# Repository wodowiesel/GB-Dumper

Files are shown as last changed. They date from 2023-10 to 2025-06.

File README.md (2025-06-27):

# GB-Dumper - Gameboy Cartridge Dumper

The GB-Dumper is a **PCB** project for Gameboy cartridge dumps/backups via Arduino __Nano__

&amp; USB-connection with the SPI-Protocol, so you can read ROM and read / write to RAM.

The new configured software and custom PCB is compatible with +5V (mostly USB) Arduino Nano or similar.

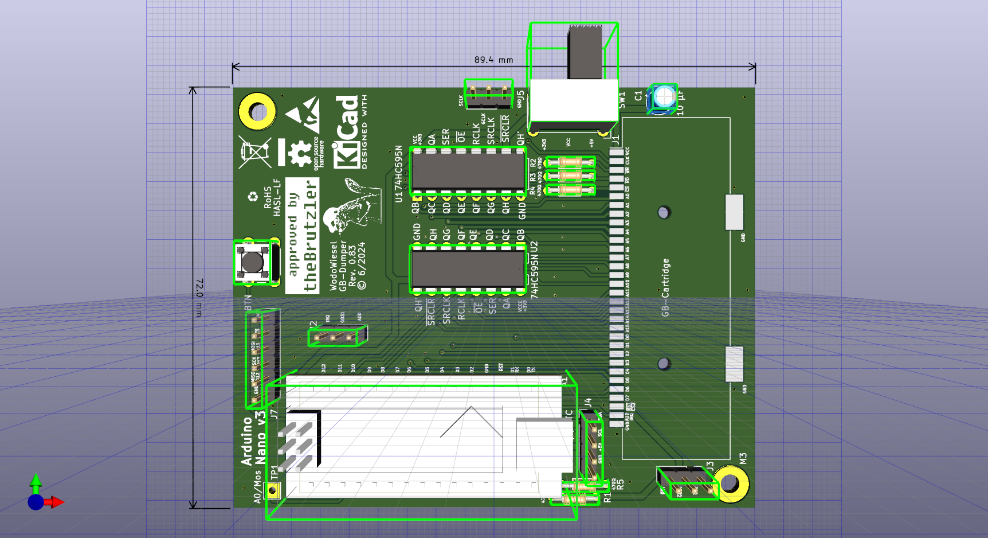
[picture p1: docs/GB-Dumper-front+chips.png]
PCB


Compatibility list:

- Gameboys (Revisions):

:heavy_check_mark: Classic & Original (DMG0 & DMG)

:heavy_check_mark: Color (CGB0 & CGB)

:heavy_check_mark: Pocket & Lite (PGB & LGB)

:heavy_check_mark: Micro (MGB)

:heavy_check_mark: Advance & SP (AGB0 & AGB)

[:heavy_check_mark: BrutzelBoy (BB) custom]

- Cartridges:

:heavy_check_mark: Class/Type A (grey+colors)

:heavy_check_mark: Class B Dual (black)

:heavy_check_mark: Class C (transparent/clear)

:heavy_check_mark: Class D (Advance GBA) -> 3.3V Logic, manual switch

:heavy_check_mark: Class X (special)

:heavy_check_mark: compatibility jumpers for pin 30 /RES + /CS2 
                   & pin 31 VIN/AUDIO + IRQ (functions wip!)

- Functions:

  - GB:

    :heavy_check_mark: Reading full header on PC/Serial

    :heavy_check_mark: Dump ROM on PC

    :heavy_check_mark: Dump RAM on PC

    :heavy_check_mark: Write RAM on Cartridge

    :white_circle: Dump ROM/RAM on SD

  - GBA:

    :heavy_check_mark: Reading full header on PC/Serial

    :white_circle: Dump ROM on PC

    :white_circle: Dump RAM on PC

    :white_circle: Write RAM on Cartridge

    :white_circle: Dump ROM/RAM on SD

# DISCLAIMERS

**This is still "work-in-progress (WIP)/experimental"

I do NOT take any kind of warranty/responsibility for damages/data losses!**

**You can use this at your own risk without guarantees and put device on non conductive surface or enclosure!**

If you like the new design you are free to share it!

Have fun and save the retro world :)

## HARDWARE

- 1x Arduino Nano v3.x (or Uno for old versions) + mini-USB-Cable + IDE

- 1x Custom PCB by WodoWiesel (wodowiesel@quantentunnel.de)

  (or from orig. GBCartReader for Uno)

- 2x flat M3 screws and an enclosure - optional

- 2x SN-74HC595 Shift-Registers from Texas Instruments

- 5x 470 (or 330) Ohm Resistors – pull-ups on active low & impedance matching

- 1x 2-position (3-pin) switch SPDT

- 1x Gameboy Cartridge 32-pin Slot

- 1x push-button - optional

- 1x ~10 uF Capacitor (pol.) - optional/recommended

- 3x Jumpers (required) -> default to GB DMG (marked as dot)

- Female Pin headers/sockets for the chips - or solder it directly

  * 1x 30-pin for Arduino

  * 2x 16-pin for shift register

- Male headers

  * 3x 3-pin (required)

  * 1x 4-pin (I²C RTC/Display - optional)

  * 1x 6-pin (SPI SD-Card - optional)

- 1x Soldering iron

- solder + flux + IPA etc.

## SOFTWARE

- It is based on GBCartRead v1.8 Rev 1.2 - Gameboy Cart Reader by insideGadgets, but impoved and smaller.

- Board based Gameboy Cartridge Reader & Writer which uses

  a C program or Python script to interface via USB with Cartridge directly.

- It allows you to dump your ROM (game), read & write the RAM (saves).

- Works with old Arduino Due-milanove and Uno, but requires wiring & code changes!)

-  Dependencies:

   a. Py

   - Download and install Python 3.2+ or higher (https://www.python.org/download/)

   - Lib: pySerial (https://pypi.python.org/pypi/pyserial/)

   b. C

   - Check dependencies cygwin64 & gcc compiler are installed.

## HOW TO USE

0. Set GB clock-pin jumper to default GND pin (arduino clock only for development/debug purposes 4/16 MHz).

   Reset pin can be set optionally to low to +5V pin if you want to soft-reset control (may need extra code).

1. Open the \GBCartRead_v1.3.x_Arduino_WodoWiesel\GBCartRead_v1.3.x_Arduino_WodoWoiesel.ino file

   with Arduino IDE. Note down and select your COM port number in use (std. Nr.3).

   You can find this out from the Arduino IDE (2) by going to Tools -> Serial port.  

   Then set the identical baudrate as in the py/c-program and flash it to your Arduino.

2. There are two choices to communicate with the Arduino – using the C program or the Python program.

  - Python Program:

  a. Open up the “GB-Dumper-v1.8_Rev1.3.x_Py_Interface.py” script by right clicking it and selecting “Edit with IDLE”.

  b. Then set the identical COM port & baudrate as in the arduino ino-program,

   save and press F5 to run it via py-reader.bat as admin.

  c. A new window will appear, after 2-3 seconds you’ll have some options available.

 - C Program:

   a. Open config.ini and change the COM port & baudrate identical to your Arduino is connected on and save the file.

   b.  Check paths in Makefile and cmaker.bat and run it as admin to compile it.

   c. Run “GBCartRead_v1.3.x_C_Interface.exe” in Windows terminal as admin or re-compile the source for your OS.

3. At this stage you should insert your Gameboy cartridge and press the power button,

   the power LED should light up.

4. Press 0 to read the header and verify that it looks correct. If it doesn’t look correct,

   press the power button to power off the Gameboy cartridge, remove and re-insert it and power it up again.

5. Press 1 to Dump the ROM, 2 to Backup your RAM or 3 to Load your RAM file.

   Hashes (#) will start printing every few seconds and a file called <gametitle>[.gb]

   or *.sav will be created if you chose option 1 or 2.

   If you choose option 3, it will load the save from <gametitle>.sav.

   It’s a good idea to verify your save files too by running the ROM when the save file is present in BGB.

## SPECIALS, CHECKSUMS & MEMORY

1. There are some cartridges which don't quite conform to cartridge header standards or require something out of the ordinary.
   
   For example the EVERDRIVE cartridges uses .srm instead of the more common .sav format and consumes less power than the EZ-Flash.
   
   For further technical infos and datasheets take a good look into the Documentation folder!!

3. GB audio pin (VIN analog) / IRQ (digital) base function is already built-in (wip!), but needs changes for rare games! :construction:

   The /RST and /CS2 pins got own compatibility functions thanks to [joaopauloap](https://github.com/joaopauloap/arduino-gba-dumper).

4. Formatting

   If you're on Linux or Mac make sure the Windows style line endings (CRLF) don't get removed and write a shell script.

5. CRC/Verification/Validation

   This file [GB/C](/docs/gb.txt) stores the ROM names and the CRC32 checksums of the complete ROM and are used only for

   verification at the end of the dumping process.

   Example:

   From: [OSCR](https://github.com/sanni/cartreader/tree/master/sd/)

   Name: 007 - The World Is Not Enough (USA, Europe).gb

   CRC32: E038E666

   It is recommend verifying your Gameboy ROM using BGB (a Gameboy emulator) or

   run validator.bat as admin via ```xgbfix.exe -v -p -d <gametitle>[.gb(c)]``` (should not contain spaces).

   Original can be found in the git project called [ASMotor](https://github.com/asmotor/asmotor/).

   -> My easier validation can be done via the [validator.bat](/code-pc/validator/validator.bat)

   or executable [xgbfix.exe](/code-pc/validator/xgbfix.exe).

6. Memory

  A memory IO-map on the standard GB can be found in the docs [here](/docs/gb-memory-maps.png).

   The file [WisdomTree](/docs/Wisdom_Tree.txt) contains memory address informations and exceptions.

   Additional articles (https://gbdev.gg8.se/wiki/articles/MBC7#Ax8x_-_EEPROM_.28Read.2FWrite.29)

7. CI

   Arduino Workflow [CI](.github/workflows/main.yaml) just for debug.

## REVISION HISTORY

v1.8 Rev 1.3.1 (28 June 2024) by WodoWiesel
- pcb 0.83
- lot more comments and documentation
- CLK switchable (default to GND or unconnected)
- added optional button pin
- added debug test point A0 for mosfet
- /RST & /CS2 (digital) switchable + functions wip
- VIN (analog) & IRQ (digital) switchable + functions wip

v1.8 Rev 1.2 (29 September 2023) by WodoWiesel
- pcb 0.7
- added CRC game informations
- added memory info, links & CI
- adapted pin configuration for new Arduino Nano
- Optimized & detailed Makefile
- added optional display pins
- added logos & pin labels

v1.8 Rev 1.1 (11 March 2022) by WodoWiesel
- pcb v0.6
- added reset pin interrupt
- added pull-up active low resistors
- added Audio/VIN (into the card) pin support for cartridges
- added more stable common ground-plane connectivity
- added M3 mounting holes

-------

v1.8 Rev 1 (28 May 2016)
- Re-add checking for non-printable ASCII characters code that was removed when cleaning up code
- Added custom cartridge files for Wisdom Tree games (thanks Benjamin E.)

v1.8 (21 March 2016)
- Added Nintendo Logo check and compare so you can tell if the cartridge is being read correctly
  (sometimes the title was read ok but the ROM dump wasn't correct)
- Added missing cartridge RAM support
- Cleaned up code

v1.7 Rev 2 (10 February 2016)
- Added checking for non-printable ASCII characters in Gameboy header and replaced them with underscores

v1.7 Rev 1 (17 February 2015)
- Fixed clockPin to change correct port - PB5 (thanks Anna)

v1.7 (7 February 2015) *Only compatible with Gameboy Cart Shield v1.3*
- Added interrupt for button on A1 to switch P-mosfet on A0 that powers the cartridge
- Changed so at startup it doesn't display the Game Cartridge header

v1.6 (3 January 2015)
- Speed increase by using a higher baud rate (400 Kbit from 57.6Kbit) and using hardware SPI (thanks David R.)
- Changed SCK from pin 12 to pin 13 for SPI
- RAM writing speed increase by continually sending 64bytes data from PC and pausing for 5 ms in-between
  (Compatible with Gameboy Cart Shield v1.2 if you connect pins 12 and 13 together)

v1.5 (15 November 2014)
- Speed increases by using direct PORT writing/reading and sending 64 bytes at a time
  (thanks Frode vdM.)
- Compacting functions (thanks Frode vdM.)
- Delays when pulsing WR/RD/MREQ pins reduced to a few NOP cycles

v1.4.2 (14 November 2014)
- Fixed gameTitle array length issue (thanks Frode vdM. and David R.)
- Added Gameboy Camera support (thanks Frode vdM. fvdm1992@yahoo.no)

v1.4.1 (3 January 2014)
- Changed wrPin from pin 13 to A3 to suit Gameboy Cart Shield v1.2

v1.4 (30 August 2013)
- Added gbcartread.exe program for Windows (with source)
  which can be used instead of using the Python script and is a bit faster

v1.3.1 (2 May 2011)
- Updated schematic as R19, R20 and R31 were actually acting as voltage dividers

v1.3 (9 April 2011)
- Added RAM writing ability
- Fixed MBC2 reading RAM overflow relating to the first 4 bits not being ignored properly
- Cleaned up bank select code to use BitRead instead of checking each bit ourselves
- Fixed selecting wrong RAM size when reading
- Fixed incorrect check if RAM was present before reading
- Removed unnecessary changing of data pins to inputs after MBC was initialized when reading RAM

v1.2 (2 April 2011)
- Added RAM saving ability.
- Now prints the amount of data read in 64K increments (i.e. ###64K###128K###192K)
- Changed <gametitle>.rom to <gametitle>.gb

v1.1 (21 March 2011)
- ROM reading is now fully automated.
- The Game Title, MBC type, ROM size and RAM size are presented in the Python script.

v1.0 (19 March 2011)
- Reading ROM only, user to change the maximum ROM bank to read

## CREDITS

 :copyright: 2021-2024 WodoWiesel

 Github (https://github.com/wodowiesel/)

 Twitch (https://www.twitch.com/wodowiesel/)

 Instagram (https://www.instagram.com/wodowiesel)

 YT (https://www.youtube.com/@wodowiesel)

 The new design was checked by the electrical engineer theBrutzler

 (https://github.com/theBrutzler/ & https://www.twitch.com/theBrutzler/)

 => For secondary project for the retro brutzelboy-dumper adapter (https://github.com/wodowiesel/brutzelboy-dumper)

 The new optimized PCB was designed with free KiCAD 8.x software (https://www.kicad.org/)

 :heavy_exclamation_mark: The PCB should be produced at a manufacturer

 (like PCBWay/JLCPCB) with the RoHS lead-free option for environmental protection.

 Original: :copyright: 2011-2016 by [insideGadgets](https://github.com/insidegadgets/GBCartRead/) support@insidegadgets.com

## LICENSES

Not for commercial and/or criminal usage!

- Hardware

   CERN Open Hardware License Version 2 - Weakly Reciprocal

   Short identifier CERN-OHL-W-2.0

   [LICENSE Source](https://spdx.org/licenses/CERN-OHL-W-2.0.html)

- Software

   This work is licensed under a Creative Commons Attribution-NonCommercial 3.0 Unported License.

   [CCANC](http://creativecommons.org/licenses/by-nc/3.0/)

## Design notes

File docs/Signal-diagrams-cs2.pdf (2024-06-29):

Read ROM
First the two least significant of address have to be latched (CS, falling edge), so the pins A0..15 can be used by the cartridge to send data (RD, falling edge). Any subsequent falling edge of RD (with CS still set to 0) will signal the cartridge to send next 16 bits (the address will be automatically incremented inside). It is important to note that the most significant byte of address should be kept correct at all times by the dumper.

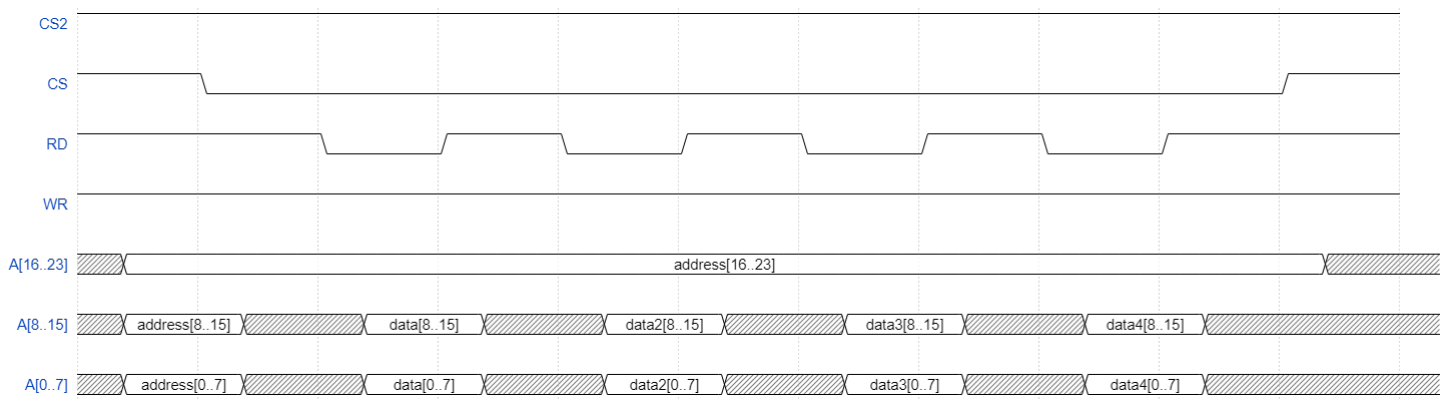
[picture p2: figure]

Read RAM
The procedure is very simple, falling edge of CS2 selects RAM. The address should be sent by the dumper via pins A0..15, while pins A16..23 should be in a high impedance state. Falling edge of RD signal the cartridge to sent the data byte (pins A16..23). CS2 should be kept low during the entire process.

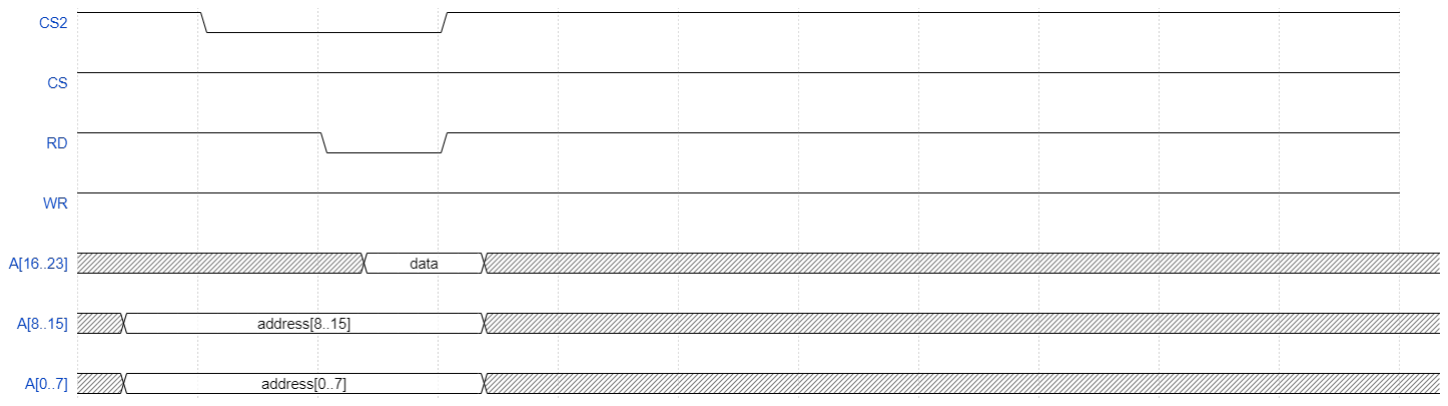
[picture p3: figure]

Write to RAM (sRAM)/Send a command to RAM (flash) The data byte and the address should be prepared first on pins A0..23. Then CS2 should be switched to 0 (RAM chip select) and after some time, WR should be lowered as well. The falling edge will send the command to the RAM chip.

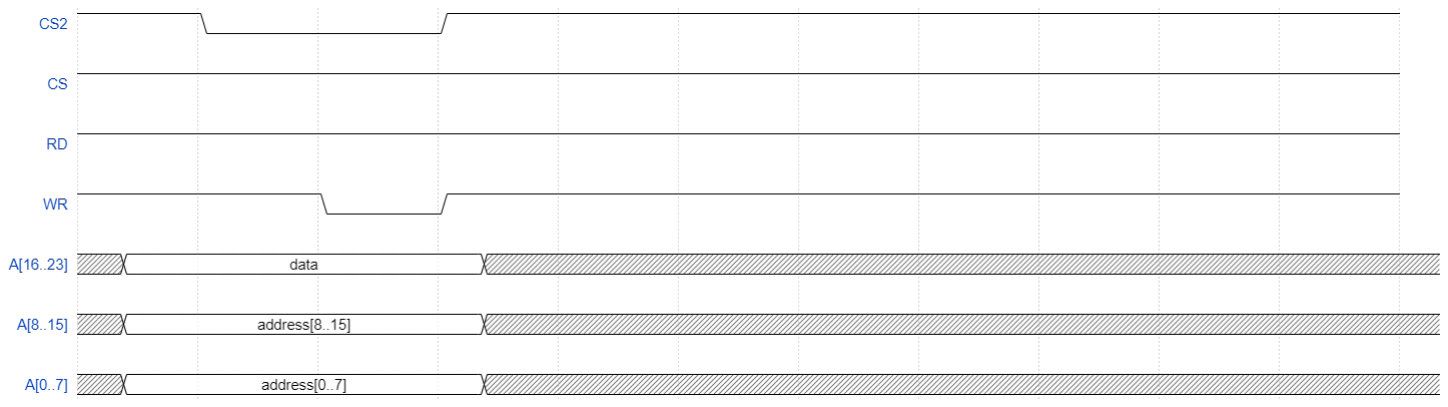
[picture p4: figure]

RAM commands (flash, from the official MX29L1611 datasheet)

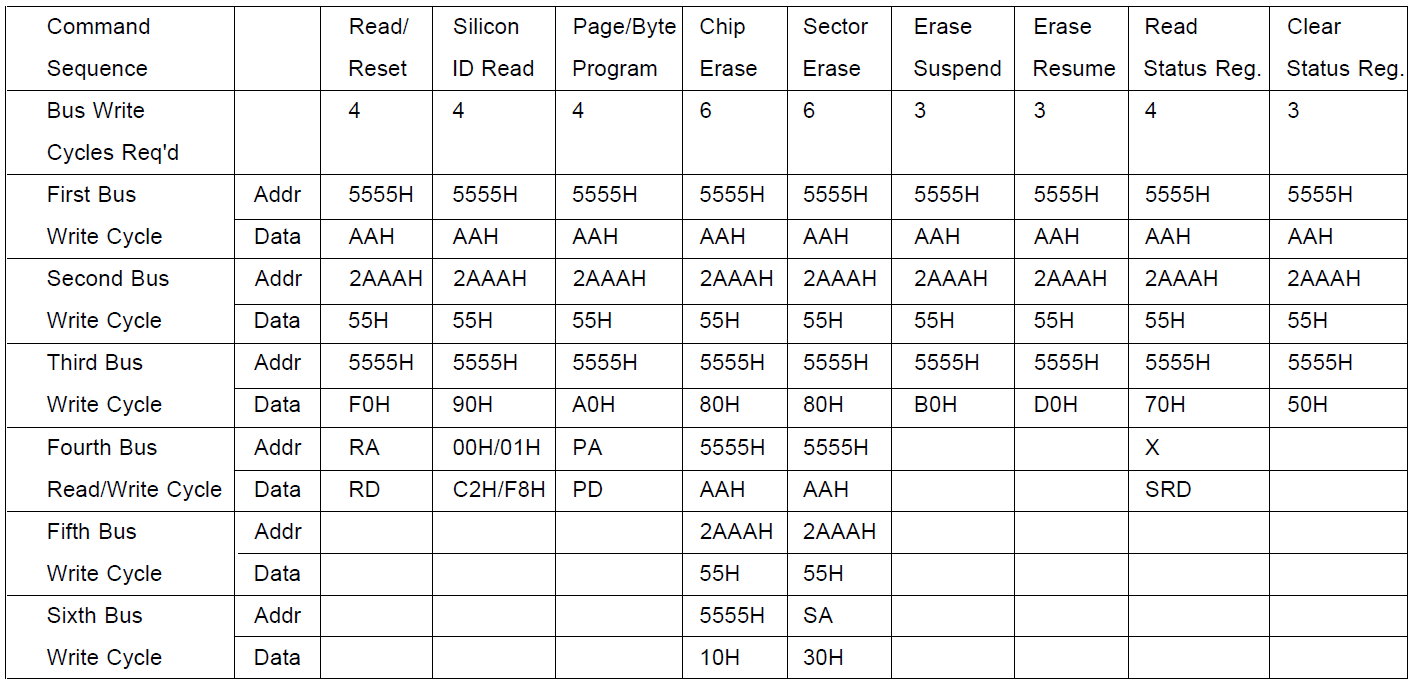
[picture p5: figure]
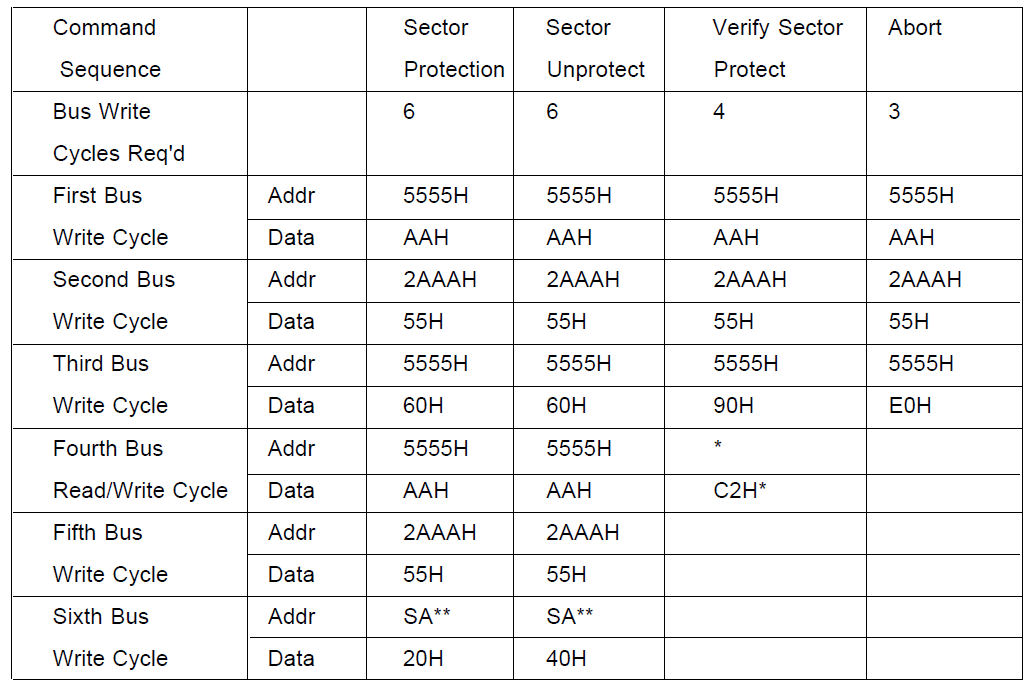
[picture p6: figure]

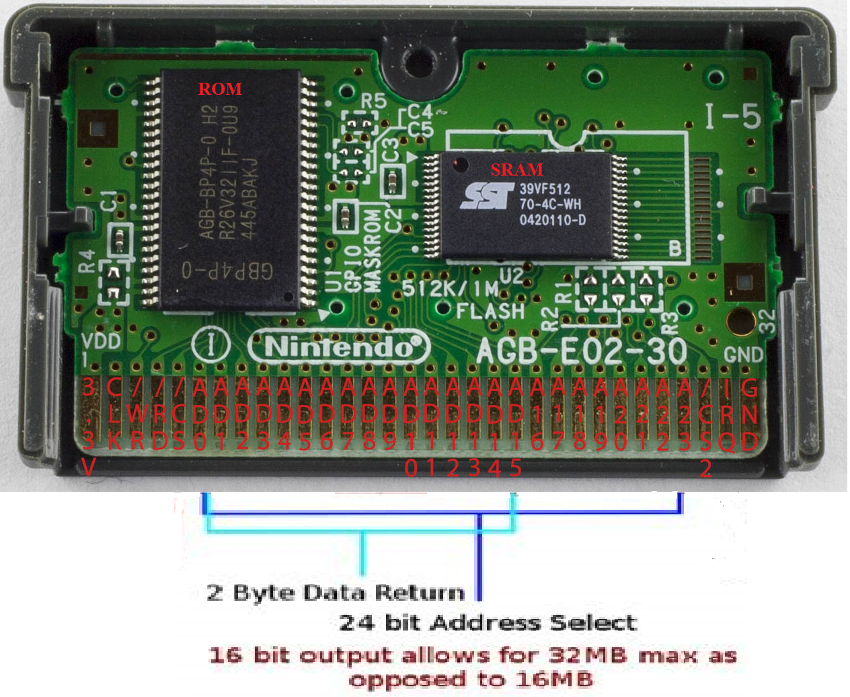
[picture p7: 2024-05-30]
docs/gba-pinout.png

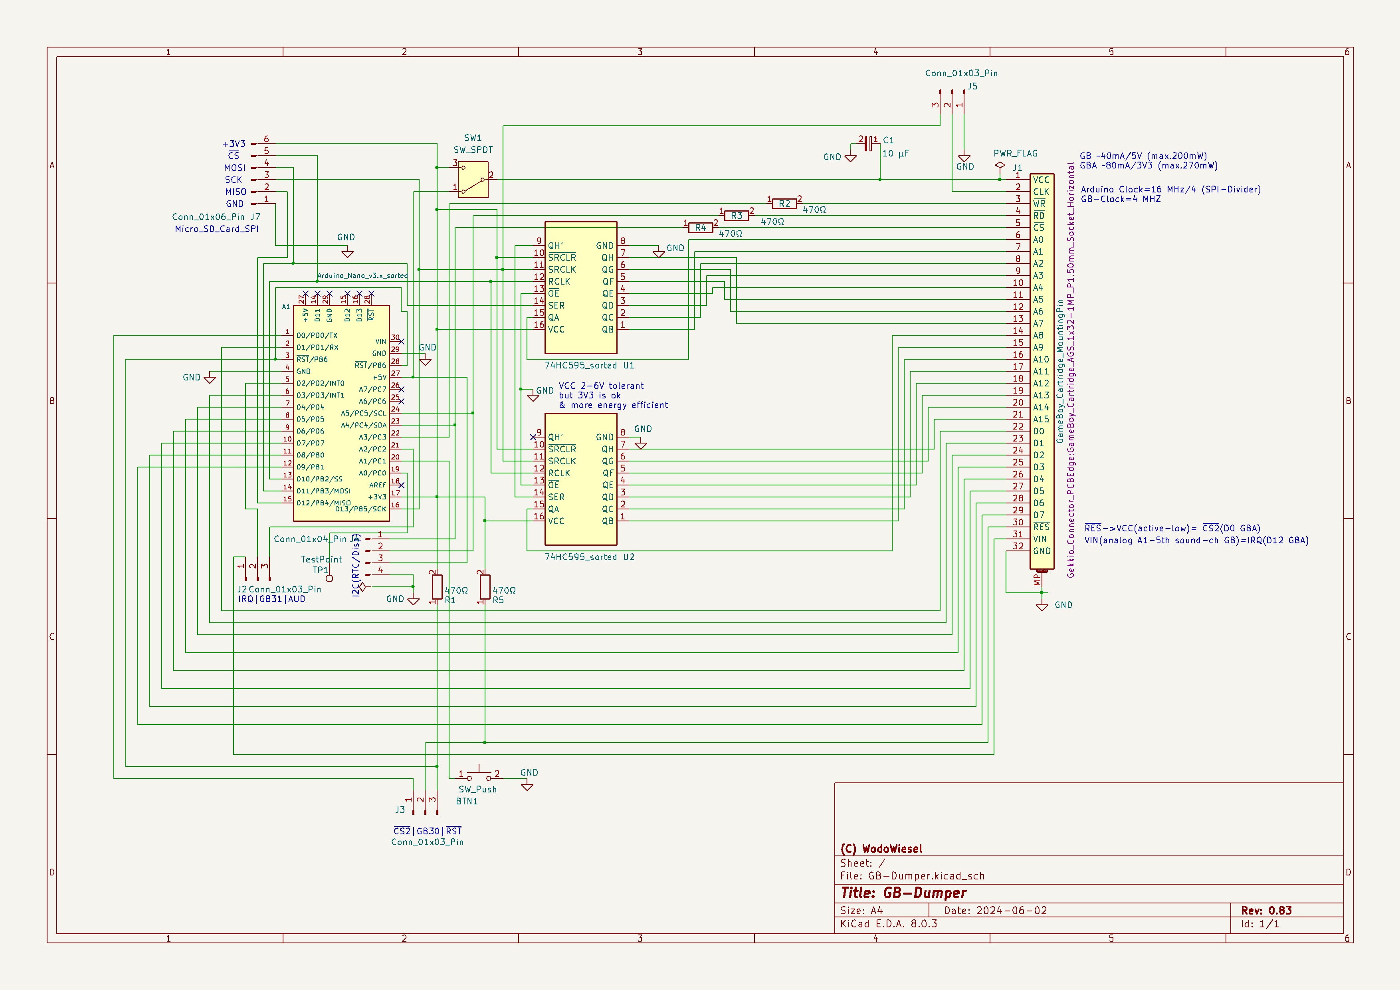
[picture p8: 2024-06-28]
docs/GB-Dumper-schematics.png

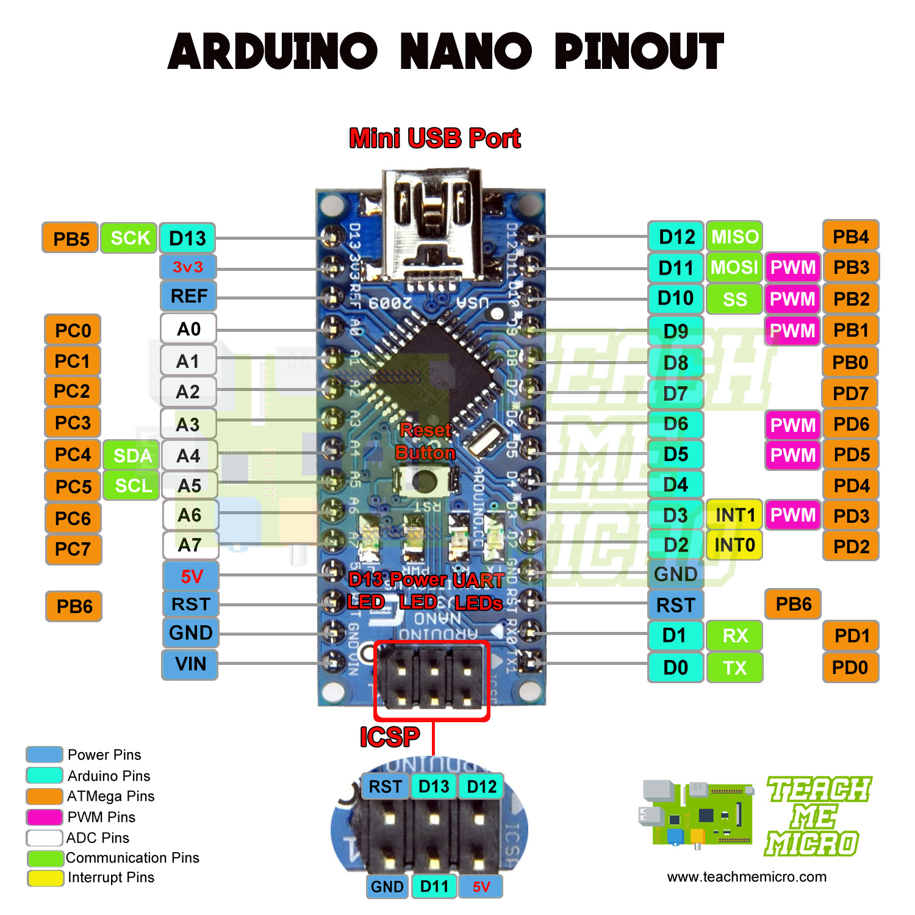
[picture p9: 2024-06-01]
docs/Arduino-Nano-pinout.png

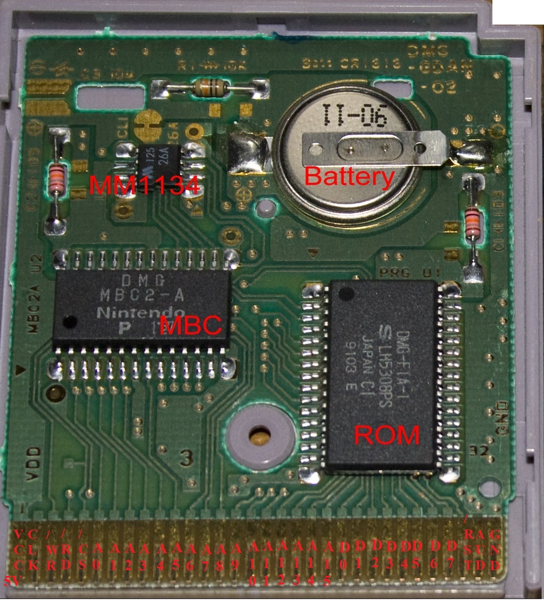
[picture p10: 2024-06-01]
docs/gb-pinout.png

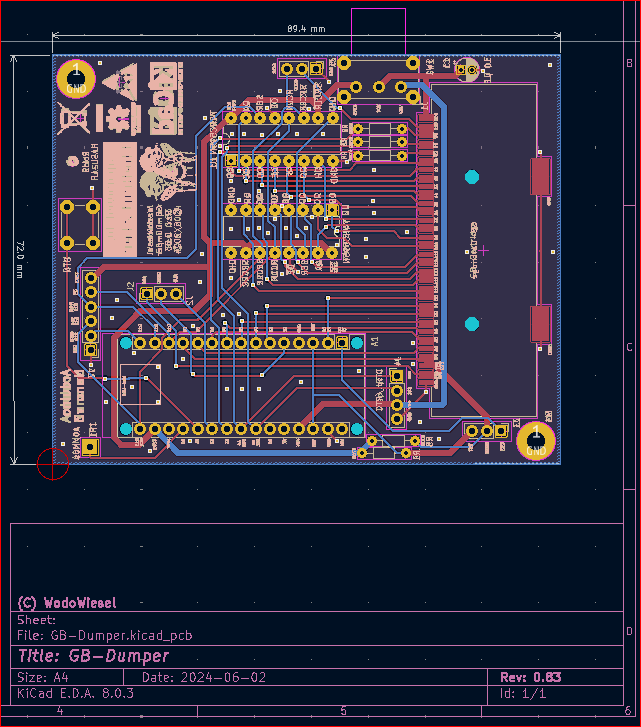
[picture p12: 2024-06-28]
docs/GB-Dumper-PCB-Sheet.PNG

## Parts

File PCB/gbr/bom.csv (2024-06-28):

ID | Bezeichner | Footprint | Stückzahl | Bezeichnung | Anbieter und Referenz
1 | J1 | GameBoy_Cartridge_AGS_1x32-1MP_P1.50mm_Socket_Horizontal | 1 | GameBoy_Cartridge_MountingPin
2 | BTN | SW_PUSH_6mm | 1 | SW_Push
3 | U2,U1 | DIP-16_W7.62mm | 2 | 74HC595_sorted
4 | J4 | PinHeader_1x04_P2.54mm_Vertical | 1 | Conn_01x04_Pin
5 | SW1 | SW_E-Switch_EG1224_SPDT_Angled | 1 | SW_SPDT
6 | R1,R3,R5,R4,R2 | R_Axial_DIN0204_L3.6mm_D1.6mm_P7.62mm_Horizontal | 5 | 470Ω
7 | C1 | CP_Radial_D4.0mm_P2.00mm | 1 | 10 µF
8 | J3,J2,J5 | PinHeader_1x03_P2.54mm_Vertical | 3 | Conn_01x03_Pin
9 | TP1 | TestPoint_THTPad_2.5x2.5mm_Drill1.2mm | 1 | TestPoint
10 | A1 | Arduino_Nano_WithMountingHoles | 1 | Arduino_Nano_v3.x_sorted
11 | J7 | PinHeader_1x06_P2.54mm_Vertical | 1 | Conn_01x06_Pin

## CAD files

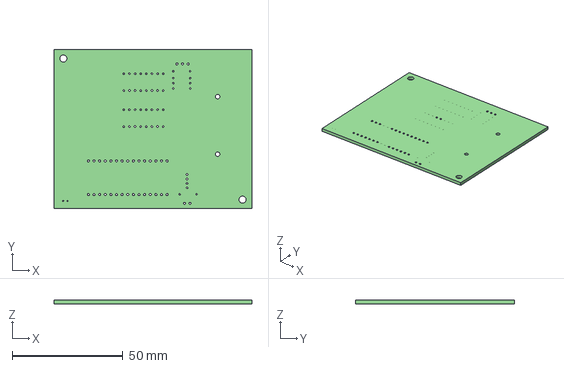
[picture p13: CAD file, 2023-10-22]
PCB/export/GB-Dumper.step
89.5 x 72.0 x 1.60 mm

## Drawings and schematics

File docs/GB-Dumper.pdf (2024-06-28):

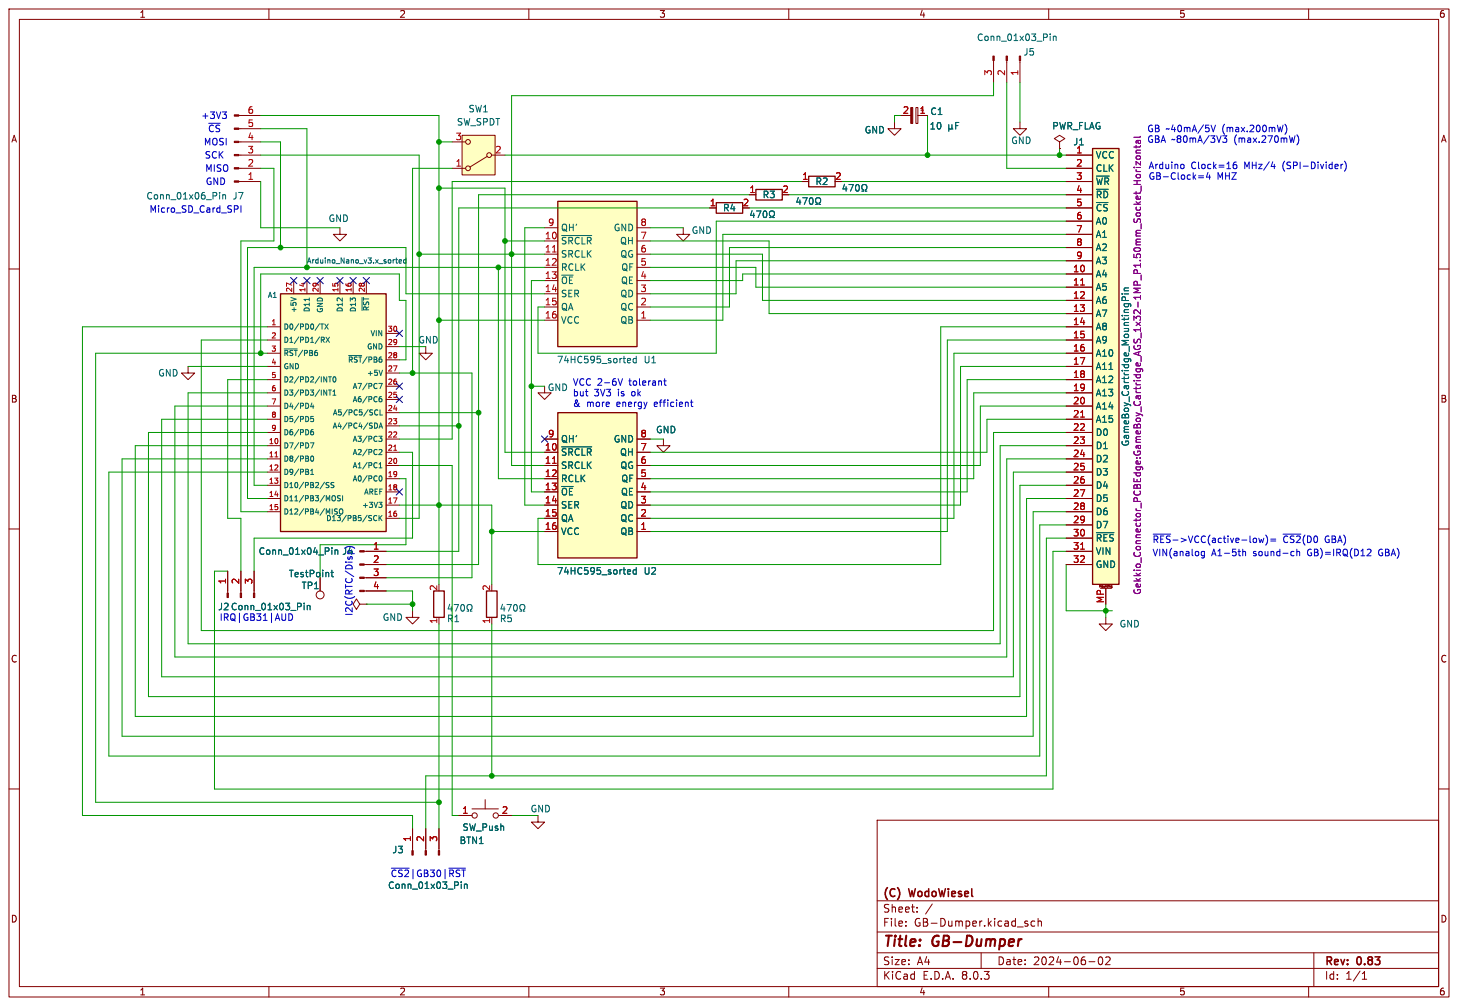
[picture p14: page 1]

IRQ|GB31|AUD MOSI MISO

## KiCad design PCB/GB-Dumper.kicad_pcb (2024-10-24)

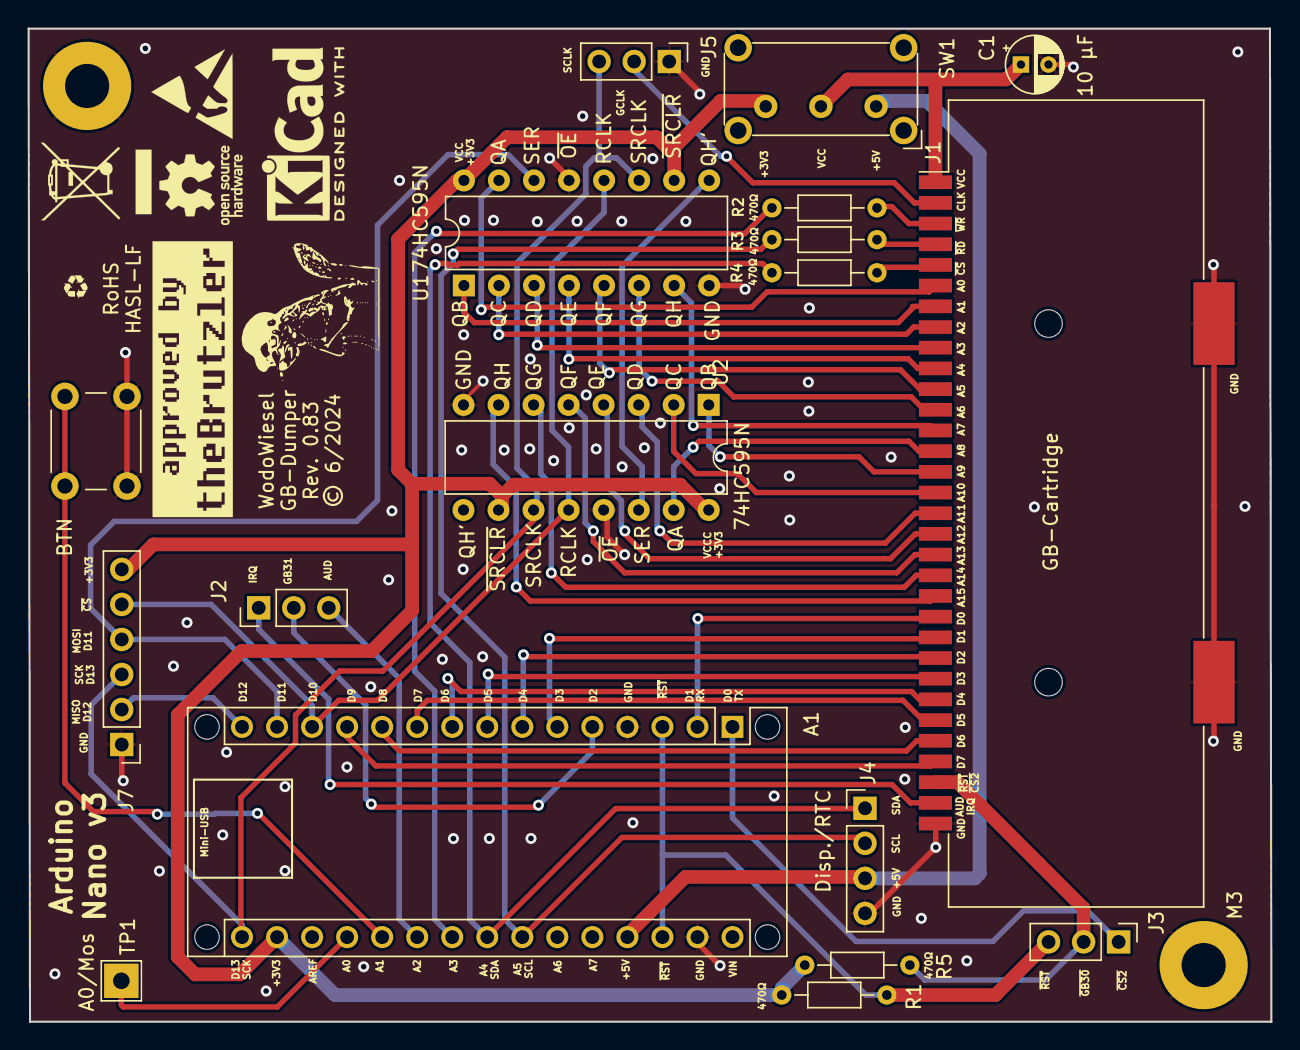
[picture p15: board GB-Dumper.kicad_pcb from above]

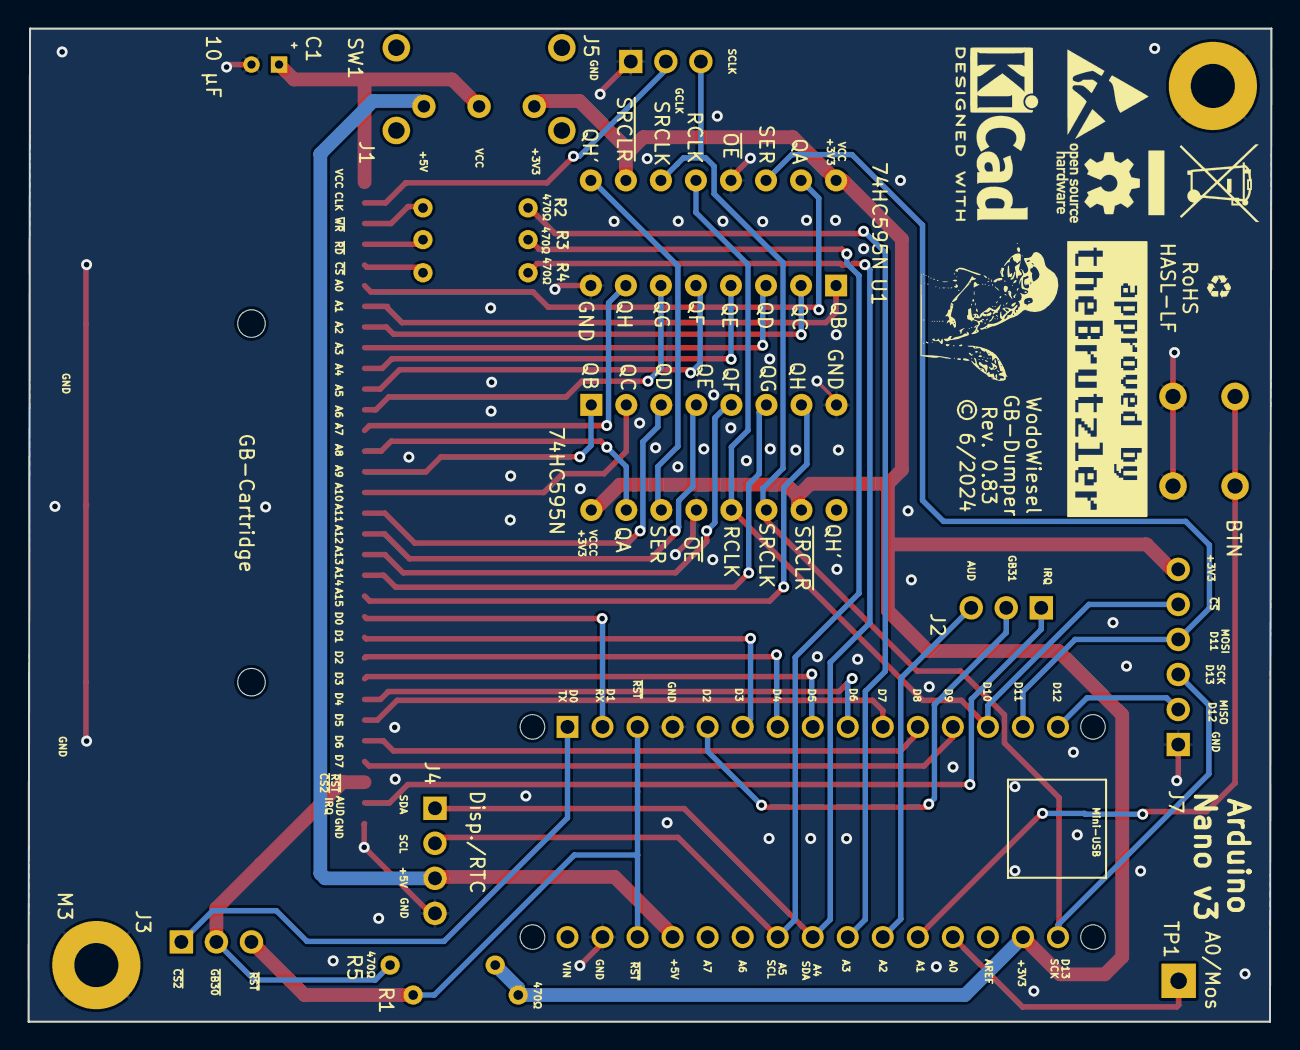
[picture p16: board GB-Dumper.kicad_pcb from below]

Board: 2 copper layers, 90.1 x 72.0 mm, 33 parts (7 on the bottom side), 48 nets.

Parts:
A1: Arduino_Nano_v3.x_sorted; Arduino_Nano_WithMountingHoles
BTN: SW_Push; SW_PUSH_6mm
C1: 10 µF; CP_Radial_D4.0mm_P2.00mm
G1, G1*: LOGO; approved_theBrutzler
G2, G2*: LOGO; wiesel-kicad-back-white
G3, G3*: LOGO; recycling-symbol-kicad
J1: GameBoy_Cartridge_MountingPin; GameBoy_Cartridge_AGS_1x32-1MP_P1.50mm_Socket_Horizontal
J2, J3, J5: Conn_01x03_Pin; PinHeader_1x03_P2.54mm_Vertical
J4: Conn_01x04_Pin; PinHeader_1x04_P2.54mm_Vertical
J7: Conn_01x06_Pin; PinHeader_1x06_P2.54mm_Vertical
R1, R2, R3, R4, R5: 470Ω; R_Axial_DIN0204_L3.6mm_D1.6mm_P7.62mm_Horizontal
REF0, REF0*: OSHW-Logo_5.7x6mm_SilkScreen
REF1*, REF2: KiCad-Logo2_5mm_SilkScreen
REF2**: ESD-Logo_6.6x6mm_SilkScreen
REF4*, REF5: WEEE-Logo_5.6x8mm_SilkScreen
REF888**, REF999**: MountingHole_3.2mm_M3_Pad
SW1: SW_SPDT; SW_E-Switch_EG1224_SPDT_Angled
TP1: TestPoint; TestPoint_THTPad_2.5x2.5mm_Drill1.2mm
U1, U2: 74HC595_sorted; DIP-16_W7.62mm

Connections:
GND: A1.4 (GND), A1.29 (GND), BTN.2, C1.2, J1.32 (GND), J1.MP, J4.4, J5.1, J7.1, REF888**.1, REF999**.1, U1.8 (GND), U1.13 (~OE), U2.8 (GND), U2.13 (~OE)
unnamed: A1.17 (+3V3), J7.6, R1.2, R5.2, SW1.3 (C), U1.10 (~SRCLR), U1.16 (VCC), U2.10 (~SRCLR), U2.16 (VCC)
unnamed: A1.27 (+5V), J4.3, SW1.1 (A)
unnamed: A1.19 (A0/PC0), TP1.1
unnamed: A1.20 (A1/PC1), BTN.1
unnamed: A1.21 (A2/PC2), J2.3
unnamed: A1.22 (A3/PC3), R2.1
unnamed: A1.23 (A4/PC4/SDA), J4.1, R4.1
unnamed: A1.24 (A5/PC5/SCL), J4.2, R3.1
unnamed: A1.1 (D0/PD0/TX), J3.1
unnamed: A1.2 (D1/PD1/RX), J1.22 (D0)
unnamed: A1.5 (D2/PD2/INT0), J2.2
unnamed: A1.6 (D3/PD3/INT1), J1.23 (D1)
unnamed: A1.7 (D4/PD4), J1.24 (D2)
unnamed: A1.8 (D5/PD5), J1.25 (D3)
unnamed: A1.9 (D6/PD6), J1.26 (D4)
unnamed: A1.10 (D7/PD7), J1.27 (D5)
unnamed: A1.11 (D8/PB0), J1.28 (D6)
unnamed: A1.12 (D9/PB1), J1.29 (D7)
unnamed: A1.13 (D10/PB2/SS), J7.5, U1.12 (RCLK), U2.12 (RCLK)
unnamed: A1.14 (D11/PB3/MOSI), J7.4, U1.14 (SER)
unnamed: A1.15 (D12/PB4/MISO), J7.2
unnamed: A1.16 (D13/PB5/SCK), J5.3, J7.3, U1.11 (SRCLK), U2.11 (SRCLK)
unnamed: J1.6 (A0), U1.15 (QA)
unnamed: J1.7 (A1), U1.1 (QB)
unnamed: J1.8 (A2), U1.2 (QC)
unnamed: J1.9 (A3), U1.3 (QD)
unnamed: J1.10 (A4), U1.4 (QE)
unnamed: J1.11 (A5), U1.5 (QF)
unnamed: J1.12 (A6), U1.6 (QG)
unnamed: J1.13 (A7), U1.7 (QH)
unnamed: J1.14 (A8), U2.15 (QA)
unnamed: J1.15 (A9), U2.1 (QB)
unnamed: J1.16 (A10), U2.2 (QC)
unnamed: J1.17 (A11), U2.3 (QD)
unnamed: J1.18 (A12), U2.4 (QE)
unnamed: J1.19 (A13), U2.5 (QF)
unnamed: J1.20 (A14), U2.6 (QG)
unnamed: J1.21 (A15), U2.7 (QH)
unnamed: J1.2 (CLK), J5.2
unnamed: C1.1, J1.1 (VCC), SW1.2 (B)
unnamed: J1.31 (VIN), J2.1
unnamed: J1.5 (~CS), R4.2
unnamed: J1.4 (~RD), R3.2
unnamed: J1.30 (~RES), J3.2, R5.1
unnamed: J1.3 (~WR), R2.2
unnamed: A1.3 (~RST/PB6), A1.28 (~RST/PB6), J3.3, R1.1
unnamed: U1.9 (QH'), U2.14 (SER)

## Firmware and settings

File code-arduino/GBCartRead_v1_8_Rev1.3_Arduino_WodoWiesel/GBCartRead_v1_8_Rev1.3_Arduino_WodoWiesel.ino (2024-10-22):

/*
  GBCartRead
  Version: 1.8 Rev 1.2

  Author: Alex from insideGadgets (https://www.insidegadgets.com)
  github: (https://github.com/insidegadgets/GBCartRead)
  Created: 18/03/2011
  Modified: 26/05/2016

  GBCartRead is an Arduino based Gameboy Cartridge Reader which uses a C program or python
  script to interface with the Arduino. GBCartRead allows you to dump your ROM,
  save the RAM and write to the RAM.
  Works with Arduino Duemilanove, Uno and Nano.
  Will work for other Arduinos too with VCC = +5V,
  but requires wiring changes!!
-----------------------------------
  UPDATE: This code was changed to be compatible for Arduino NANO and a custom PCB!!

  Version: 1.8 Rev 1.3
  Author: WodoWiesel
  github: (https://github.com/wodowiesel/GB-Dumper)
  Last Modified: 28. June 2024
*/

// for REVISION 0.6 of the GB-Dumper Board
// compatible with Cartridges Classic (Original) + Color + Pocket + Micro :
// Class/Type A (grey+colors), Class B Dual (black), Type C (transparent/clear)
// NOT compatible with Class D (Advance GBA) -> 3.3V Logic
// cartridge internal coin battery Li-cell normally +3V CR2025, sometimes 2032, CR1616 GBA
#include <string.h>
#include <util/delay.h>
#include <SPI.h>
#include <Wire.h>
#include "pindeclarations.h"
//optional
//#include <Adafruit_SSD1306.h> // OLED_I2C load displ driver before graph-lib!
//#include <Adafruit_GFX.h> //core graph api

//----------------- General Config
// baud calc https://wormfood.net/avrbaudcalc.php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
int baud = 19200; // best rate with minimal errors for serial connection, max 115200, 6-8% errors
/*info for clock 
The problem is that the GB is using a base 2 frequency clock crystal,
not a base 10 one. Ie, 1MiHz = 1024*1024 Hz = 1048576 Hz,
where "normally" you'd use 1 MHz = 1000000 Hz. But that's easy to overcome with new frequency tables.
*/
// Edit these in pindelcarations.h too if needed!
// Digital Pins-> D-Numbers
uint8_t gb30cPin = 0; // /CS2 -> Ar_Pin1 PD0 D0 TX digital
uint8_t gb22Pin = 1;   // GB_D0 -> Ar_Pin2 PD1 D1 RX
uint8_t gb31iPin = 2;  // GB_IRQ  -> Ar_Pin5 PD2 INT0 digital if needed for interrupts too!
uint8_t gb23Pin = 3;   // GB_D1 -> Ar_Pin6 PD3 INT1
uint8_t gb24Pin = 4;   // GB_D2 -> Ar_Pin7 PD4 D4
uint8_t gb25Pin = 5;   // GB_D3 -> Ar_Pin8 PD5 D5
uint8_t gb26Pin = 6;   // GB_D4 -> Ar_Pin9 PD6 D6
uint8_t gb27Pin = 7;   // GB_D5 -> Ar_Pin10 PD7 D7
uint8_t gb28Pin = 8;    // GB_D6 -> Ar_Pin11 PB0 D8
uint8_t gb29Pin = 9;    // GB_D7 -> Ar_Pin12 PB1 D9
uint8_t latchPin = 10;  // RCLK -> Ar_Pin13 PB2 D10 SS/CS
uint8_t dataPin = 11;   // SER -> Ar_Pin14 PB3 D11 MOSI
uint8_t sd_miso = 12;   // SD_SPI -> Ar_Pin15 PB4 D12 MISO https://github.com/rust-console/gbatek-gbaonly/blob/gh-pages/index.md#gbainterruptcontrol idk why? old
uint8_t clockPin = 13;  // /SRCLK -> Ar_Pin16 PB5 D13 SCK(SPI), switchable clock for cartridge 4MHz
uint8_t gb30Pin = 28; // /RST + /RES + /RESET + SCLR + VCC -> Ar_Pin3&28 PB6 PCINT14 -> also /CS2 for advance
uint8_t gb32Pin = 29; // GND + /OE -> Ar_Pin4&29

// Analog Pins
uint8_t mosfetControlPin = A0; // Mosfet -> Ar_Pin19 PC0 internal
uint8_t BTNPin = A1;  // /BTN -> Ar_Pin20 PC1 PCINT9 Button for resets
uint8_t AudioPin = A2;  // VIN/AUDIO_IN DMG gn31 -> Ar_Pin21 PC2
uint8_t wrPin = A3;   // /WR -> Ar_Pin22 PC3
uint8_t mreqPin = A4; // /CS -> Ar_Pin23 PC4 SDA
uint8_t rdPin = A5;   // /RD -> Ar_Pin24 PC5 SCL

// DISPLAY CONFIG
// right Bit (LowBit) not counted -> 0x78/2=0x3C
/*
#define I2C_ADDRESS 0x3C // 0x78->3C, 0x7A->3D, 0x74->3A alternative
display.begin(SSD1306_SWITCHCAPVCC, I2C_ADDRESS);
display.cp437(true);
display.clearDisplay();
display.setTextColor(WHITE);
display.setTextSize(1);
display.setCursor(0,0);
*/

//--------------------------- setup pins
// https://gbdev.io/pandocs/Power_Up_Sequence.html
uint8_t nintendoLogo[] = {0xCE, 0xED, 0x66, 0x66, 0xCC, 0x0D, 0x00, 0x0B, 0x03, 0x73, 0x00, 0x83, 0x00, 0x0C, 0x00, 0x0D,
                          0x00, 0x08, 0x11, 0x1F, 0x88, 0x89, 0x00, 0x0E, 0xDC, 0xCC, 0x6E, 0xE6, 0xDD, 0xDD, 0xD9, 0x99,
                          0xBB, 0xBB, 0x67, 0x63, 0x6E, 0x0E, 0xEC, 0xCC, 0xDD, 0xDC, 0x99, 0x9F, 0xBB, 0xB9, 0x33, 0x3E
                         };

char gameTitle[17];
uint16_t cartridgeType = 0;
uint16_t romSize = 0;
uint16_t romBanks = 0;
uint16_t ramSize = 0;
uint16_t ramBanks = 0;
uint16_t ramEndAddress = 0;

void setup() {
  //analogReference(DEFAULT); // AREF
  pinMode(latchPin, OUTPUT); // RCLK
  pinMode(clockPin, OUTPUT); // SRCLK + SCK
  pinMode(dataPin, OUTPUT); // D11 MOSI
  pinMode(rdPin, OUTPUT); // A5
  pinMode(wrPin, OUTPUT); // A3
  pinMode(mreqPin, OUTPUT); // /CS
  pinMode(mosfetControlPin, OUTPUT); // A0
  pinMode(gb30Pin, OUTPUT); // /RES + /RST + /RESET -> Ar_Pin3&27 INPUT => std as active (if GND) LOW -> pull-up
  pinMode(gb30cPin, OUTPUT); // /CS2 PD0/D0/TX
  pinMode(AudioPin, OUTPUT); // AUDIO_IN gb_31
  pinMode(gb31iPin, OUTPUT); // IRQ gba

  //mosfetPin_high; // mosfet off
  PORTC |= (1 << PC0);

  // Set pins as inputs
  DDRB &= ~((1 << PB0) | (1 << PB1) | (1 << PB4)); // D8 to D13 datapin | (1<<PB3) , D12 clock | (1<<PB5) , latch (1<<PB2) , AUDIO_IN
  // DDRC &= ~((1<<PC0) | (1<<PC3) | (1<<PC4) | (1<<PC5)); // A0,3,4,5
  DDRD &= ~((1 << PD1) | (1 << PD3) | (1 << PD4) | (1 << PD5) | (1 << PD6) | (1 << PD7)); // D0 to D7 , D2(IRQ=PD2):  | (1 << PD2)

  rd_wr_mreq_off();

  // Setup pin interrupt for button
  PCMSK1 = (1 << PCINT9); // A1 Ar_Pin20 PC1
  PCICR = (1 << PCIE1);
  
  //serial settings https://www.arduino.cc/reference/tr/language/functions/communication/serial/begin/
  Serial.begin(baud, SERIAL_8N1); // for 4/16 MHz clock, default bit mode
  //Serial.println("\nInit done \n");
}

//----------- main
void loop() {

  // Decode input
  char readInput[10];
  uint8_t readCount = 0;

  // Wait for serial input
  while (Serial.available() <= 0) {
    delay(200);
  }
  while (Serial.available() > 0) {
    char c = Serial.read();
    readInput[readCount] = c;
    readCount++;
  }
  //readInput[readCount] = '\0';
  readInput[16] = '\0';
  
  // Cartridge Header
  if (strstr(readInput, "HEADER")) {
    rd_wr_mreq_reset();

    // Read cartridge title and check for non-printable text
    for (uint16_t romAddress = 0x0134; romAddress <= 0x143; romAddress++) {
      char headerChar = (char) read_byte(romAddress);
      if ((headerChar >= 0x30 && headerChar <= 0x57) || // 0-9
          (headerChar >= 0x41 && headerChar <= 0x5A) || // A-Z
          (headerChar >= 0x61 && headerChar <= 0x7A)) { // a-z
          //Serial.println(headerChar);
        /*
         * MULICARD MBCs & EMS etc https://gbdev.gg8.se/wiki/articles/Memory_Bank_Controllers
          A header matching any of the following is detected as EMS mapper:
          Header name is "EMSMENU", NUL-padded
          Header name is "GB16M", NUL-padded
          Cartridge type ($0147) = $1B and region ($014A) = $E1
        */
      }
      gameTitle[16] = '\0';
      
      cartridgeType = read_byte(0x0147); // MBC type should be specified in the byte at 0147h of the ROM
      romSize = read_byte(0x0148);
      ramSize = read_byte(0x0149);

      // ROM banks
      romBanks = 2; // Default 32K
      if (romSize >= 1) { // Calculate rom size
        romBanks = 2 << romSize;
      }

      // RAM banks
      ramBanks = 0; // Default 0K RAM
      if (cartridgeType == 6) {
        ramBanks = 1;
      }
      if (ramSize == 2) {
        ramBanks = 1;
      }
      if (ramSize == 3) {
        ramBanks = 4;
      }
      if (ramSize == 4) {
        ramBanks = 16;
      }
      if (ramSize == 5) {
        ramBanks = 8;
      }

      // RAM end address
      if (cartridgeType == 6) {
        ramEndAddress = 0xA1FF;  // MBC2 512 bytes (nibbles)
      }
      if (ramSize == 1) {
        ramEndAddress = 0xA7FF;  // 2K RAM dez
      }
      if (ramSize > 1) {
        ramEndAddress = 0xBFFF;  // 8K RAM
      }

    }

    // Nintendo Logo Check
    uint8_t logoCheck = 1;
    uint8_t x = 0;
    for (uint16_t romAddress = 0x0104; romAddress <= 0x133; romAddress++) {
      if (nintendoLogo[x] != read_byte(romAddress)) {
        logoCheck = 0;
        break;
      }
      x++;
    }

      Serial.println(gameTitle);
      Serial.println(cartridgeType);
      Serial.println(romSize);
      Serial.println(ramSize);
      Serial.println(logoCheck);
    }

    // Dump ROM (game)
   else if (strstr(readInput, "READROM")) {
      rd_wr_mreq_reset();
      uint16_t romAddress = 0;

      // Read number of banks and switch banks
      for (uint16_t bank = 1; bank < romBanks; bank++) {
        if (cartridgeType >= 5) { // MBC2 and above
          write_byte(0x2100, bank); // Set ROM bank
        }
        else { // MBC1
          write_byte(0x6000, 0); // Set ROM Mode
          write_byte(0x4000, bank >> 5); // Set bits 5 & 6 (01100000) of ROM bank
          write_byte(0x2000, bank & 0x1F); // Set bits 0 & 4 (00011111) of ROM bank
        }
        if (bank > 1) {
          romAddress = 0x4000;
        }

        // Read up to 7FFF (dez 32767) per bank
        while (romAddress <= 0x7FFF) {
          uint8_t readData[64];
          for (uint8_t i = 0; i < 64; i++) {
            readData[i] = read_byte(romAddress + i);
          }

          Serial.write(readData, 64); // Send the 64 byte chunk
          romAddress += 64;
        }
      }
   }

    // Read RAM (save)
   else if (strstr(readInput, "READRAM")) {
      rd_wr_mreq_reset();

      // MBC2 Fix (unknown why this fixes reading the ram, maybe has to read ROM before RAM?)
      read_byte(0x0134); // dez 308

      // if cartridge have RAM test
      if (ramEndAddress > 0) {
        if (cartridgeType <= 4) { // MBC1
          write_byte(0x6000, 1); // Set RAM Mode dez 24576
        }

        // Initialise MBC
        write_byte(0x0000, 0x0A); // dez 10

        // Switch RAM banks
        for (uint8_t bank = 0; bank < ramBanks; bank++) {
          write_byte(0x4000, bank); // dez 16384

          // Read RAM
          for (uint16_t ramAddress = 0xA000; ramAddress <= ramEndAddress; ramAddress += 64) { // 40960
            uint8_t readData[64];
            for (uint8_t i = 0; i < 64; i++) {
              readData[i] = read_byte(ramAddress + i);
            }

            Serial.write(readData, 64); // Send the 64 byte chunk
          }
        }

        // Disable RAM
        write_byte(0x0000, 0x00);
      }
    }

    // Write RAM
    else if (strstr(readInput, "WRITERAM")) {
      rd_wr_mreq_reset();

      // MBC2 Fix (unknown why this fixes it, maybe has to read ROM before RAM?)
      read_byte(0x0134);

      // check cartridge RAM
      if (ramEndAddress > 0) {
        if (cartridgeType <= 4) { // MBC1
          write_byte(0x6000, 1); // Set RAM Mode
        }

        // Initialise MBC
        write_byte(0x0000, 0x0A);

        // Switch RAM banks
        for (uint8_t bank = 0; bank < ramBanks; bank++) {
          write_byte(0x4000, bank);

          // Write RAM
          for (uint16_t ramAddress = 0xA000; ramAddress <= ramEndAddress; ramAddress++) {
            // Wait for serial input
            while (Serial.available() <= 0);

            // Read input
            uint8_t readValue = (uint8_t) Serial.read();

            // Write to RAM
            mreqPin_low;
            write_byte(ramAddress, readValue);
            asm volatile("nop");
            asm volatile("nop");
            asm volatile("nop");
            mreqPin_high;
          }
        }

        // Disable RAM
        write_byte(0x0000, 0x00);

        // Flush any serial data that wasn't processed
        Serial.flush();
      }
    }
    
    else if (strstr(readInput, "CLOCK")) {
      // test clock trigger
        clockPin_low;
        clockPin_high;
        clockPin_low;
    }
    
    else if (strstr(readInput, "GBASAVE")) {
      // dump ram special gba
        cs2_dumpsave();
    }
    
      rd_wr_mreq_off();
    ///Serial.println("Loop done \n");
}
//--- End loop!

// func definitions
  uint8_t read_byte(uint16_t address) {
    shiftout_address(address); // Shift out address

    mreqPin_low;
    rdPin_low;
    asm volatile("nop"); // Delay a little (minimum is 2 nops, using 3 to be sure)
    asm volatile("nop");
    asm volatile("nop");
    uint8_t bval = ((PINB << 6) | (PIND >> 2)); // Read data
    rdPin_high;
    mreqPin_high;

    return bval;
  }

  void write_byte(uint16_t address, uint8_t data) {
    // Set pins as outputs
    DDRB |= ((1 << PB0) | (1 << PB1) | (1 << PB4)); // | (1<<PB2) | (1<<PB4),D8 to D13, datapin | (1<<PB3), clock | (1<<PB5)
    // DDRC |= ((1<<PC0) | (1<<PC3) | (1<<PC4) | (1<<PC5)); // A0, 3 to 5
    DDRD |= ((1 << PD1) | (1 << PD2) | (1 << PD3) | (1 << PD4) | (1 << PD5) | (1 << PD6) | (1 << PD7)); // D0 to D7

    shiftout_address(address); // Shift out address

    // Clear outputs and set them to the data variable
    PORTB &= ~((1 << PB0) | (1 << PB1) | (1 << PB4)); // | (1<<PB2) | (1<<PB4)D8 to D13, clock | (1<<PB3) | (1<<PB5)
    // DDRC &= ~((1<<PC0) | (1<<PC3) | (1<<PC4) | (1<<PC5)); // A0, 3 to 5
    PORTD &= ~((1 << PD1) | (1 << PD3) | (1 << PD4) | (1 << PD5) | (1 << PD6) | (1 << PD7)); // D0 to D7, | (1 << PD2)

    PORTD |= (data << 2);
    //PORTC |= (data << 2); // bitshift length unknown atm!
    PORTB |= (data >> 6);

    // Pulse WR
    wrPin_low;
    asm volatile("nop");
    wrPin_high;

    // Set pins as inputs
    DDRB &= ~((1 << PB0) | (1 << PB1) | (1 << PB4)); // | (1<<PB2) | (1<<PB4), D8 to D13, datapin | (1<<PB3), clock | (1<<PB5)
    // DDRC &= ~((1<<PC0) | (1<<PC3) | (1<<PC4) | (1<<PC5)); // A0, 3 to 5
    DDRD &= ~((1 << PD1) | (1 << PD2) | (1 << PD3) | (1 << PD4) | (1 << PD5) | (1 << PD6) | (1 << PD7)); // D0 to D7
  }

  // Use the shift registers to shift out the address
  void shiftout_address(uint16_t shiftAddress) {
    SPI.transfer(shiftAddress >> 8);
    SPI.transfer(shiftAddress & 0xFF);

    latchPin_low;
    asm volatile("nop");
    latchPin_high;
  }

  // Turn /RD, /WR and MREQ to high so they are deselected (reset state)
  void rd_wr_mreq_reset(void) {
    rdPin_high; // /RD off
    wrPin_high; /// WR off
    mreqPin_high; // MREQ off
  }

  // Turn /RD, /WR and MREQ off as no power should be applied to GB Cart
  void rd_wr_mreq_off(void) {
    rdPin_low;
    wrPin_low;
    mreqPin_low; // /CS
  }

  // Setup pin interrupt for button
  void (*resetFunc)(void) = 0; // create a standard reset function

  void soft_reset(void) {
    //Serial.println("Button Reset check \n");
    resetFunc();
    //digitalWrite(gb30Pin, LOW); // deactivate /RST
    //digitalWrite(gb30Pin, HIGH); // activate /RST (method without button / soft reset)
  }

  void reset_button(void) { // active-low jumper on board should be set!
    //Serial.println("Reset button check \n");
    // Serial.println("Reset pressed \n");
    // https://forums.nesdev.org/viewtopic.php?t=15689
     gb30Pin_low;  // is open-drain, 100h-00h /CS2+/RST addr
    // gb30Pin_high;
  }

  // --------------experimental!!! if ready it will be built-in to the upper code!!!
  // joaopauloap suggestions https://github.com/joaopauloap/arduino-gba-dumper
  unsigned int readDataBus() {
    Serial.println("CS2 read databus \n");
    unsigned int s = ((PINB & 0b00000011) << 6) | ((PIND & 0b11111100) >> 2); // 0b00000011 = hex&dez 3, 11111100 = 0xFC = 252 dez
    return (s);
  }

  void latchaddress(unsigned int addr) {
    digitalWrite(latchPin, LOW);
    shiftOut(dataPin, clockPin, MSBFIRST, (addr >> 8)); // clock ? idk
    shiftOut(dataPin, clockPin, MSBFIRST, addr);
    digitalWrite(latchPin, HIGH);
  }

  void cs2_dumpsave() { // digital active-low
    Serial.println("Dumping GBA Save \n");
    //digitalWrite(mreqPin, HIGH);  // CS Disable ROM
    digitalWrite(gb30cPin, LOW);
    for (unsigned long addr = 0; addr < 0x1FFF; addr++) {
      latchaddress(addr);
      digitalWrite(rdPin, LOW);
      delayMicroseconds(2);
      digitalWrite(rdPin, HIGH);
      int d = readDataBus();
      Serial.write(d);
    }

    digitalWrite(gb30cPin, HIGH);
    Serial.println("CS2 dump done \n");
    // may need adaption in C/Py code on pc app!
    // -> not sure what data is exatly transfered ? need more info from pdf !!
  }
  // end  suggestion


  ISR(gb31iPin_vect) { // alternative for attached pin
    Serial.println("ISR check \n");
  }

  void IRQ_handler(void) {
    Serial.println("IRQ check \n");
    pinMode(gb31iPin, INPUT);  // INPUT_PULLUP Set the pin as input with pull-up resistor, not sure normally no resistor needed , std output
    gb31iPin_high;
    attachInterrupt(digitalPinToInterrupt(gb31iPin), IRQ_GBA, RISING);
    // https://www.arduino.cc/reference/de/language/functions/external-interrupts/attachinterrupt/
    // maybe only with INT0&1, D2&3 on nano for attaching digital,wip -> may need change for the pin gb23 (d0) or gb24 (d1)
    // => gb23 from D2 to D1!!!!! change stuff in main funtions!!!
    // Handle PC0 interrupt (rising edge of the gameboy CLK)
    gb31iPin_low;
  }

    void IRQ_GBA(void) {
    Serial.println("attach check \n");
  }

  void AUDIO_GB(void) {
    Serial.println("AUDIO check \n");
    //may need PORTB activation above! wip but no priority
    /*
      VIN/AUDIO can output up to 0.6V and total stays less than 3V (5 x 0.6V = 3V).
      So I guess that software using VIN should not put an audio volume higher
      than 12.8 on each channel, which would mean 0xC or 0xD.
  links to clock and audio channels
    https://gbdev.gg8.se/forums/viewtopic.php?id=10
    https://dhole.github.io/post/gameboy_cartridge_emu_2/ only for STM32
    */
  }

  // sd card via spi
  void sd_card_action(void) {
    Serial.println("sd_card_action check \n");
    //add later with thebrutzler
  }

  //------------- end experimental
  // interrupt check for main
  ISR(PCINT1_vect) {
    _delay_ms(200);
    if (PINC & (1 << PC1)) { // Invert mosfet control pin on A1
      PORTC ^= (1 << PC0);
    }

    while (PINC & (1 << PC1)); // Wait for button release
    _delay_ms(200);

    // Check if mosfet is on or off (inverted as it's a P mosfet)
    if (PINC & (1 << PC0)) {
      SPI.end(); // End SPI
      
      rd_wr_mreq_off(); // Set everying low
      gb31Pin_low; // AUDIO
      gb31iPin_low; // IRQ
      gb30cPin_low;  //CS2
      //gb30Pin_low; // maybe use reset pins for hardware reset
      latchPin_low;
      dataPin_low;
      clockPin_low;
 
      _delay_ms(200);
      asm volatile ("jmp 0"); // Jump to address 0 (soft reset)

    }
    else {
      SPI.begin(); // Setup SPI
      // alternative SPI Settings(uint32_t clock, uint8_t bitOrder, uint8_t dataMode);
      // Max SPI speed is always half of the CPU clock.
      //SPI.setClockDivider(SPI_CLOCK_DIV2); // half cock speed, gb dmg clock 4 MHz (DIV4 default)
      SPI.setBitOrder(MSBFIRST); // most-significant bit first
      SPI.setDataMode(SPI_MODE0); // clock polarity and phase (leading edge Sample rising, trailing edge Setup falling)
      SPI.beginTransaction(SPISettings(4000000, MSBFIRST, SPI_MODE0)); // alternative func
    }

  }
  //EOF
  

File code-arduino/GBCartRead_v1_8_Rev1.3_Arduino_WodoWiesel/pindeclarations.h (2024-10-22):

 /*
 UPDATE: This code was changed to be compatible for Arduino NANO and a custom PCB!!

 Author: WodoWiesel
 github: (https://github.com/wodowiesel/GB-Dumper)
 Last Modified: 28 June 2024
 Compativble with PCB v0.83!
 */

#ifndef PINDECLARATIONS_H_
#define PINDECLARATIONS_H_
#define HW 3 // hardware revision v3.x nano
#define FW 4.4
#define OZ 28.800 //xtal oscilator 28,800 MHz
/*
// AVR definitions for Arduino nano! -> check your cocnnections again!

Registers:
https://docs.arduino.cc/retired/hacking/software/PortManipulation/
https://deepbluembedded.com/arduino-port-manipulation-registers-example/
// PORTA (only nano 33/uno?)
#define PA0 0
#define PA1 1
#define PA2 2
#define PA3 3
#define PA4 4
#define PA5 5
#define PA6 6
#define PA7 7 // ??
*/

// PORTB
#define PB0 0 // D8
#define PB1 1 // D9
#define PB2 2 // D10
#define PB3 3 // D11/MOSI
#define PB4 4 // D12/MISO
#define PB5 5 // D13/SCK(SPI)
#define PB6 6 // /RES
//#define PB7 7 // not on nano

// PORTC
#define PC0 0 // A0
#define PC1 1 // A1
#define PC2 2 // A2
#define PC3 3 // A3
#define PC4 4 // A4
#define PC5 5 // A5
#define PC6 6 // A6
#define PC7 7 // A7

// PORTD
#define PD0 0 // D0/TX
#define PD1 1 // D1/RX
#define PD2 2 // D2/INT0
#define PD3 3 // D3/INT1
#define PD4 4 // D4
#define PD5 5 // D5
#define PD6 6 // D6
#define PD7 7 // D7

// Assignments for functions to specific ports
#define mosfetPin_high PORTC  |= (1<<PC0); // Pin19 A0
#define mosfetPin_low  PORTC  &= ~(1<<PC0); // not sure if | or & inverted?

#define BTNPin_high   PORTC |= (1<<PC1); // /RST Button for soft reset, Pin20 A1, not used atm
#define BTNPin_low    PORTC &= ~(1<<PC1); // /RST Button for soft reset, Pin20 A1, not used atm


// A2/PC2 not used

#define wrPin_high    PORTC |= (1<<PC3); // /WR Pin22 A3
#define wrPin_low     PORTC &= ~(1<<PC3);

#define mreqPin_high  PORTC |= (1<<PC4); // /CS Pin23 A4
#define mreqPin_low   PORTC &= ~(1<<PC4);

#define rdPin_high    PORTC |= (1<<PC5); // /RD Pin24 A5
#define rdPin_low     PORTC &= ~(1<<PC5);

#define latchPin_high PORTB |= (1<<PB2); // RCLK/SS Pin13 D10  ->CS???
#define latchPin_low  PORTB &= ~(1<<PB2);

#define dataPin_high  PORTB |= (1<<PB3); // MOSI Pin14 D11
#define dataPin_low   PORTB &= ~(1<<PB3);

#define clockPin_high PORTB |= (1<<PB5); // SRCLK/SCK Pin 16 D13 (SPI)
#define clockPin_low PORTB &= ~(1<<PB5);

// extra pins
/*
#define gb22Pin_high  PORTD |= (1<<PD1); // GB_D0  Pin2 D1 RX    
#define gb22Pin_low   PORTD &= ~(1<<PD1);

#define gb23Pin_high  PORTD |= (1<<PD3); // GB_D1 Pin6 INT1 D3
#define gb23Pin_low   PORTD &= ~(1<<PD3);

#define gb24Pin_high  PORTD |= (1<<PD4); // GB_D2 Pin7 D4
#define gb24Pin_low   PORTD &= ~(1<<PD4);

#define gb25Pin_high  PORTD |= (1<<PD5); // GB_D3 Pin8 D5
#define gb25Pin_low   PORTD &= ~(1<<PD5);

#define gb26Pin_high  PORTD |= (1<<PD6); // GB_D4 Pin9 D6
#define gb26Pin_low   PORTD &= ~(1<<PD6);

#define gb27Pin_high  PORTD |= (1<<PD7); // GB_D5 Pin10 D7
#define gb27Pin_low   PORTD &= ~(1<<PD7);

#define gb28Pin_high  PORTB |= (1<<PB0); // GB_D6 Pin11 D8
#define gb28Pin_low   PORTB &= ~(1<<PB0);

#define gb29Pin_high  PORTB |= (1<<PB1); // GB_D7 Pin12 D9
#define gb29Pin_low   PORTB &= ~(1<<PB1);
*/

// special pins

#define gb30Pin_high  PORTB |= (1<<PB6); // /RES Pin3&29
#define gb30Pin_low   PORTB &= ~(1<<PB6);

#define gb30cPin_high  PORTD |= (1<<PD0); // /CS2(digital) on D0/PD0 Pin1
#define gb30cPin_low   PORTD &= ~(1<<PD0);

#define gb31Pin_high  PORTC |= (1<<PC1); // AUD_IN analog on A1 PC1 Pin21 (bits 7 & 3 of NR_50 register ) 
#define gb31Pin_low   PORTC &= ~(1<<PC1);

#define gb31iPin_high  PORTB |= (1<<PD2); // IRQ (digital) Pin5 INT0 D2 (on MISO Pin15 D12 old)
#define gb31iPin_low   PORTB &= ~(1<<PD2);

#endif /* PINDECLARATIONS_H_ */

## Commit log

2022-10-03 Initial upload PCB
    Initial upload PCB
    [GB-Dumper-B_Adhesive.dxf, GB-Dumper-B_Courtyard.dxf, GB-Dumper-B_Cu.dxf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]
2022-10-03 Initial upload PCB 2
    Initial upload PCB 2
    [GB-Dumper-B_Adhesive.gbr, GB-Dumper-B_Courtyard.gbr, GB-Dumper-B_Cu.gbr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]
2022-10-03 move KiCAD PCB to Folder
    move KiCAD PCB to Folder
    [GB-Dumper-B_Adhesive.dxf, GB-Dumper-B_Courtyard.dxf, GB-Dumper-B_Cu.dxf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]
2022-10-03 Arduino nano3 pinout & Shift-register manual
    Arduino nano3 pinout & Shift-register manual
2022-10-03 add Arduino Nano & PC app (py/c) code
2022-10-29 more cleanup
    [GB-Dumper-positions.csv]
2023-04-21 arduino ci
    arduino ci
2023-10-13 -update design to 0.7 (clk 6 rst jumpers)
    [GB-Dumper.kicad_pcb, GB-Dumper.kicad_sch]
2023-10-13 -optimized resistors, caps, routing -cleanup folders/exports
    [GB-Dumper-B_Adhesive.dxf, GB-Dumper-B_Courtyard.dxf, GB-Dumper-B_Cu.dxf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]
2023-10-13 fix typo
    [GB-Dumper.kicad_pcb]
2023-10-22 -better gnd with mounting holes -cleanup silkscreen -removes orientation crosses -generated new gerbers/exports
    [GB-Dumper-B_Adhesive.gbr, GB-Dumper-B_Courtyard.gbr, GB-Dumper-B_Cu.gbr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]
2024-02-23 better audio + cs2 + rst button support
    [GB-Dumper.kicad_pcb, GB-Dumper.kicad_sch]
2024-05-04 cleanup paths & add debug prints
2024-06-01 update arduino code to new pcb design + more docu & links
2024-06-28 PCB 0.83 update
    [GB-Dumper-B_Adhesive.gbr, GB-Dumper-B_Courtyard.gbr, GB-Dumper-B_Cu.gbr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]
2024-06-29 -edge case handling on serial -cs2 docu
2024-10-22 -QOL & print changes -debug & docu info/comments -speed up spi to gb clock 4 mhz -speed up uart baud to 19200
2024-10-22 gb cartridge plug cut
2024-10-24 -minor optimizations
    [GB-Dumper.kicad_pcb, GB-Dumper.kicad_sch]
2024-10-29 -more error handling -bump up version
    [GB-Dumper_v1.8_Rev1.3.2_Py_Interface.py]
2025-10-19 println with F() macro for efficiency
    println with F() macro for efficiency
2026-09-13 Update resistor value from 470 Ohm to 4.7 kOhm

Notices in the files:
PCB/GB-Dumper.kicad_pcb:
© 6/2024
